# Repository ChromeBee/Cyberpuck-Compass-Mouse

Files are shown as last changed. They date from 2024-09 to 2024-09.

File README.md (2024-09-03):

<h2>Description</h2>
In the late 90's / early 2000's, I bought a Forte VFX1 headgear VR headset second hand from Cash Converters. This came with a hand device they called a Cyberpuck. Both the VFX1 
and the Cyberpuck used the Earths magnetic field to determine movement. In the VFX1 this determined where the wearer was looking and in the 
case of the Cyberpuck, what hand movements the user was making.

Cyberpuck
<i>Original Cyberpuck from 1995. (Wikipedia free use image)</i>

cropped image Cyberpuck in hand
<i>My version of the cyberpuck 2024</i>

This is my version of the Cyberpuck, upgraded to be wireless. I was inspired to develop this based on an Element14 video I watched where Clem
tries to make a mouse using an IMU sensor but ends up with something you have to pick up and twist and tilt to get working.  I though, that is 
like the old Cyberpuck I used to have. 

The Cyberpuck is a 2DOF mouse that uses pitch to move the mouse pointer up and down the screen and roll to move it left and right. I can't 
remember how I used the original version but for this one, the mouse only moves if the lower button (GPIO2) is pressed. This is so you can set
it down with the mouse pointer moving unintentionally. The top button (GPIO4) provides the left mouse button functionality while the middle
button (GPIO3) is the right mouse button. <i>Please note that there is additional informations below the built instruction for those that want it.</i>

<h2>Assemby Instructions</h2>

<b>Parts List:</B>
<ul>
<li>XIAO ESPC3 micro controller</li>
<li>GY-271 - Compass sensor</li>
<li>3 6x6x5mm tactile switches</li>
<li>connecting wire</li>
<li>lipo battery with builtin BMS protection circuit of an appropriate size to fit in the case. I used a 501220.  
As you can see from the photos, there is space for a larger battery.</li>
<li>You will also need the 3D printed parts, 1 each of the side pieces and 3 of the buttons</li>
</ul>

<b>Wiring Diagram:</b>

wiring diagram

I bought all the parts except the battery from Amazon. The battery I bought from eBay.

I chose the XIAO ESP32C3 microcontroller because it was being advertised in my Google news feed at the time and I liked the small size. It has a
hardware UART (serial interface) which means that it can't simulate a mouse over the USB cable so Bluetooth has to be used. If you don't want to 
use the battery, it can be powered over USB but you still need to use Bluetooth to use it as a mouse. Other XIAO size micro controllers can be 
used but you'll need to modify the code if the pinouts are different.

photo of completed wiring

Keep the wires short when wiring things up so that everything fits inside the case.

photo of circuit in case

There is a lip to the right hand side of the bottom case where the battery is. The top lid has a matching part which slips below this lip and
using the USB access hole as a guide to ensure the two halves aren't twisted fold the two halves together. There are protrusions on the top
half of the case that fit down the side of the switches and hold it closed.

Once built download the sketch from this repositary page. The code uses two libraries. The QMC5883LCompass library so that the microcontroller can 
use the GT-271 sensor and a BLEMouse library so it can act as a Bluetooth mouse. Download the one at 
https://github.com/sirfragles/ESP32-BLE-Mouse/tree/dev The official BLEMouse library fails to compile but this version has a fix installed.

To minimise battery drain when the mouse isn't being used, the ESP32C3 will go into a deep sleep state after 2 minutes of non use. Pressing 
any of the buttons will wake it up again. The battery is recharged by plugging the microcontrollers USB port into any 5v USB power source such as a computer or power bank .

With the Cyberpuck mouse awake, Open the Bluetooth settings on whatever device you want to use it with and scan for new devices. “Cyberpuck mouse”
should appear in the list as a mouse device. Connect to it, and holding the device in your hand with the middle buttons pointing forward and the
USB connector below, press the button connected to GPIO2 (the bottom button in my case and the bottom button in the wiring diagram), and move 
your arm up, tilting from the elbow and the mouse pointer should go up, tilting the device to the side should move the pointer to the left or 
right depending on the direction of the tilt.

Here is a short demonstration followed by the device being assembled.

https://youtu.be/AyjnlBCEP1o

I don't see this replacing the traditional mouse for word processing or spreadsheet work but more as a gaming or presentation control device. I
think it would be good in a simple flight simulator or as a weapon in a simple first person shooter. I have had fun playing online mouse games,
but I keep losing to people using a traditional mouse. Maybe it is because I need more practice (or maybe I'm crap at the games).

<h2>Additional Information</h2>

prototypes
<i> how many prototypes until the final design?</i>

The GY-271 compass magnetometer uses a QMC5883L digital compass chip. A lot of the listings for this sensor board list it as having a HMC5883L
chip. Some versions of this board also have HMC5883L written on them.
This caused me to lose a lot of time as both chips offer a similar function but have different I2C address. This resulted in me getting zeros back from the I2C interface. The chip on the PCB just had 5883 written on it.
I downloaded a sketch that allowed me to see which addresses were active on the I2C bus and from that I found out that the chip
must have been a QMC5883L.

The QMCX5883Lcompass library has an example file for calibrating the chip. This tries to get the maximum and minimum values while you wave the sensor
around 360 degrees in all directions. I tried this and also captured large volumes of X, Y and Z values into a spreadsheet to analyse it. The
values given from the three directional sensors on the chip have different maximum values and different maximum values in the negative and
positive directions. This is why calibration is necessary if you need accurate direction values.

I stopped this project for several months as I had to think how to convert the 3D vector created from the 3 perpendicular sensors readings to the mouse movement I wanted. It turned out I didn't need
to as all I need is a relative change. We only need 2 DOF for this. So provided the mouse is rotated around one of its axis, the relative change in
value will give you the direction and amount.

Given the orientation of the board in the case, a roll (tilt left or right) cause a change in the Y and Z axis readings . 
A pitch change causes a change in the X and Y axis readings. For the porpose of using this as a mouse we only need to look at the change in Z readings to determine how much to move the mouse pointer in the horizontal and in what direction. The X reading is used in the same way for 
vertical movements. We can ignore the Y readings in normal use. Yawing the mouse (rotating it about the vertical axis) does cause movement on both the horizontal and vertical directions. Preventing this would mean going back to the 3D vector maths and I personally don't think it is worth the effort. Limiting our hand movements to pitch and roll is the easiest solution.

I intended this to be a wired mouse so I was surprised to find that I couldn't do that because the microcontroller I chose had a hardware UART to
communicate over USB. This means that it couldn't send mouse emulation signals over that port. I'd have to change the microcontroller or use
bluetooth. So bluetooth it was. That also meant that there was no point using USB just for power. So I'd need to add a battery and battery saving
features. Such as detecting when the device has been idle for a period and putting it in a power saving mode and be able to wake up from that.

Mapping the values from the compass sensor to mouse movements was also an interesting challenge. We want the mouse pointer to move fast across the screen
but still be able to do delicate movements. For this reason there is an exponential type mapping between the compass sensor and the steps the mouse will take.
Small tilt movements take small steps but large tilt movements cause large steps to be taken. There is a wider range of movement allowed for
small steps than large steps. This is achieved by having a mapping table that contains more small steps and as the movement gets larger and
the steps get bigger, the number of entries in the mapping table get smaller. 

The mapping table is sized based on the sum of integers up to a certain number. For ease of giving an example, i'll use the number 4. In this
case the mapping table would have 10 entries (4+3+2+1 = 10), The first 4 entries in the mapping table are filled with 1, the second 3 are filled with 2 the third 2 are filled with 3 and the last one is filled with 4. These numbers represent the number of steps the mouse will take
if that mapping entry is selected. We then need to take a reading from the compass, multiple that by 10 and divide the result by what we think is the largest number the compass can return (- the deadzone). Convert that into an integer and you should get a number between zero and ten. that we can then use to look up a mouse movement amount in the mapping table.

I might add something to the code to emulate even smaller steps. Such as emulating half steps by making the mouse only take a step every second time through the main loop for very small mouse movements. <b>update</b> I now think that the small steps are fine (comparing it to my other mouse) but I need a slower acceleration, i.e. more small steps before it starts to take bigger steps. I have added that to the code already.

Another thought I had was to have a click on and click off for mouse movements. I added that to the code but didn't like it in use. At first it seemed an improvement but I couldn't easily tell if it was on or off, so I removed it again.

I was playing the 3D maze game at https://www.chrisraff.com/3d-maze/ This is a fun game. I played it using the cyberpuck and an ordinary mouse and I found I had better scores with the cyberpuck. Finally I've found something that it is better at than a normal mouse (at least for me). 

I am still learning to use this. I keep moving my arm horizontally to move the mouse in that direction. That is not how the mouse currently works as the maths is far more complicated. And the original worked the same way mine does. Maybe I'll revisit it at some point.

<h2>License</h2>
Shield: [][cc-by-nc-sa]

This work is licensed under a
[Creative Commons Attribution-NonCommercial-ShareAlike 4.0 International License][cc-by-nc-sa].

[][cc-by-nc-sa]

[cc-by-nc-sa]: http://creativecommons.org/licenses/by-nc-sa/4.0/
[cc-by-nc-sa-image]: https://licensebuttons.net/l/by-nc-sa/4.0/88x31.png
[cc-by-nc-sa-shield]: https://img.shields.io/badge/License-CC%20BY--NC--SA%204.0-lightgrey.svg

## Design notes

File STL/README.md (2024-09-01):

STL files from the design ready for 3D printing can be found here.

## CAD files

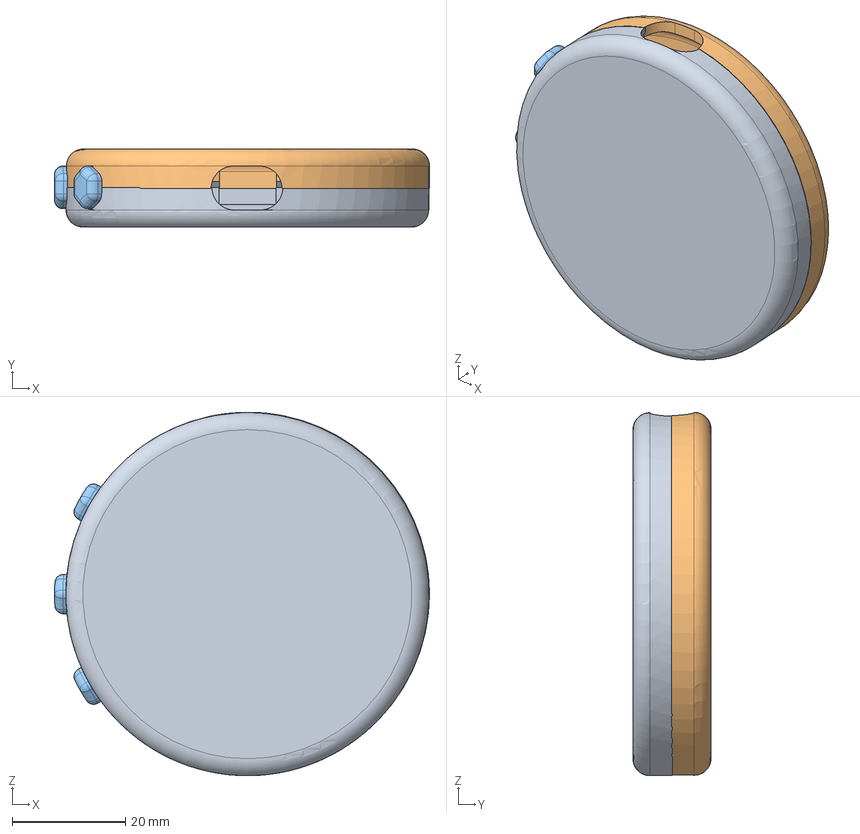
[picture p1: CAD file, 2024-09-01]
Design/Cyberpuck Compass Mouse.step
66.1 x 13.8 x 64.1 mm
side
side 2
button

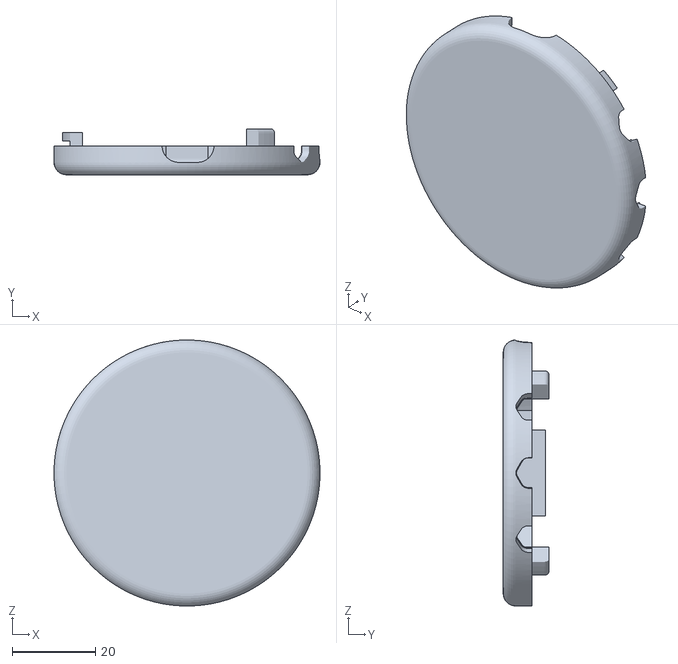
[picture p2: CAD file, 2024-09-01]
STL/compass mouse side 2.stl
64.0 x 11.0 x 64.0

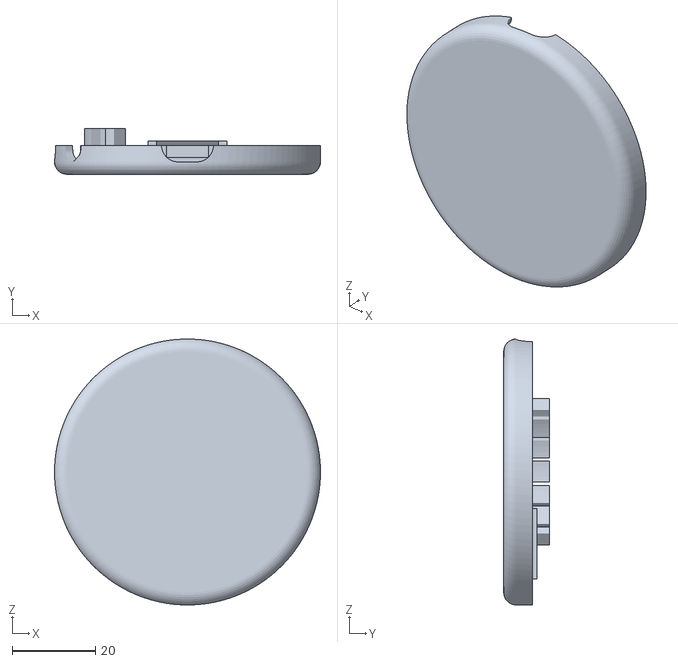
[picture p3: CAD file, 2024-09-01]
STL/compass mouse side.stl
64.0 x 11.0 x 64.0

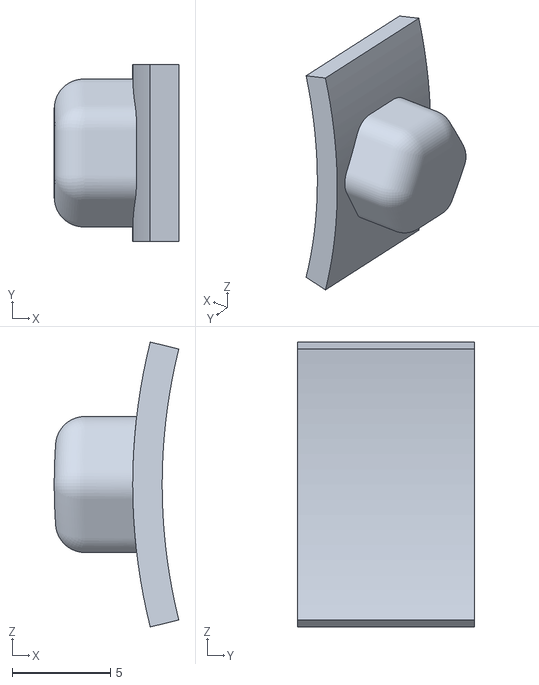
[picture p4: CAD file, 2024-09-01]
STL/button.stl
6.35 x 9.00 x 14.5

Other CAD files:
Design/Cyberpuck Compass Mouse.f3d

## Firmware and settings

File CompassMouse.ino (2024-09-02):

// Compass Mouse
// A modern version of the Forte Cyberpuck from the 1990s
// The Cyberpuck was an input device for the Forte VFX1 Headgear VR headset.
// Both the headset and the cyberpuck used the earths magnetic field to determine movement.
// in the headsets case it was used to determine where the user was looking and in the Cyberpucks case, how they moved their hand.
// It was a 2 DOF device using pitch and roll to map to Y and X.
// As well as using it with the VFX1 headset, it could be used alone as a mouse that didn't need desk space.
// this is my modern interpretation of the Cyberpuck device.
// i'm using aSeeed Studio XIAO ESP32C3 as the microcontroller and GY-271 magnetometer sensor board to detect the earths magnetic field
// it uses the QMC5883 compass sensor.
// 3 6x6x5mm tactile buttons are also used to simulate mouse buttons. All came from Amazon in the UK.
//
// This sketch needs the QMC5883LCompass library and a BleMouse library
// The default BLEMouse library doesn't compile due to change in the arduino string type introduced some time ago. Use the library below instead
//  https://github.com/sirfragles/ESP32-BLE-Mouse/tree/dev
//
/*--------------------------------------------------------------
 * Change log
 * C001 01-Sep-2024 - lengthened the mapping array to give double the space to each step value to make acceleration slower
 * -------------------------------------------------------------
 */
#include <BleMouse.h>
#include <QMC5883LCompass.h>
#include "driver/rtc_io.h"




#define MAX_COMPASS_VALUE 600.0 // assumed maximum from compass read once deadzone value is removed
#define MAX_MOUSE_MOVEMENT 7 // Maximum single step for mouse. This is what it takes when compass output is MAX_COMPASS_VALUE or higher
#define MOVEMENT_BUTTON 0 // button that enables mouse movement
#define LEFT_BUTTON 2 // button that simulates left mouse button pressed
#define RIGHT_BUTTON 1 // button that simulates right mouse button press

#define TIMEOUT 2*60*1000 // 2 minutes of inactivity will cause the ESP32 to enter deep sleep mode.

#define BUTTON_PIN_BITMASK  1ULL<<GPIO_NUM_2 | 1ULL<<GPIO_NUM_3 | 1ULL<<GPIO_NUM_4 // pins used for buttons. need bit mask for wakeup action.
gpio_num_t BTNLIST[3] = { // Button pin list - note that BUTTON_PIN_MASK will need changed if this list changes
  GPIO_NUM_2,
  GPIO_NUM_3,
  GPIO_NUM_4
};

static bool reverseX = true; // reverse mouse X direction if true
static bool reverseY = true; // reverse mouse Y direction if true

#define BLUETOOTHTIMEOUT 5*1000 // time connection is allowed to drop before trying to pair with another device
QMC5883LCompass compass;
static std::string deviceName = "Cyberpuck mouse";
BleMouse bleMouse;
// C001 - doubled the size of the map_array as it will have double the number of each value original formula was MAX_MOUSE_MOVEMENT*(MAX_MOUSE_MOVEMENT+1)/2 this is the formula for the sum of all integers upto MAX_MOUSE_MOVEMENT
int map_array[MAX_MOUSE_MOVEMENT*(MAX_MOUSE_MOVEMENT+1)]; // array that is the size all the interger values from MAX_MOUSE_MOVEMENT added together down to zero. i.e. if this were 3 it would equal 3+2+1+0

//-------------------------------------
// convert from compass value to mouse movement value
// the map_array is filled in the setup subroutine to favour small movements
int mapToMovement(float input, float max_output,float max_input) {
  int output;
  int max_index = (int)(max_output*(max_output+1)); // Size of the map array C001 - removed the divide by 2 in the integer addition formula
  
  output = input*max_index/max_input; // find the array index to use (this may be negative indicating the looked up value must be the same)
  int sgn=output/abs(output); // get the sign of the value (this gives either 1 or -1)
  //Serial.print("array index ");Serial.println(output);
  output = (abs(output)>=max_index) ? sgn*map_array[max_index-1] : sgn*map_array[abs(output)]; // check that the result is not too large then look up the step size to take
  
  return output; // return mouse step size
}

//-----------------------------------
// read buttons with debounce code included
#define DEBOUNCE_TIME 50 // number of milliseconds allowed to reach steady state
unsigned long timeSinceChange[3] = {0,0,0}; // milliseconds since switch state last changed
uint8_t lastKnownState[3] = {0,0,0}; // remember old switch state.
bool stateChanged[3] = {false,false,false};

void readAllFromButtons(uint8_t *buttonValues){
  for(int i=0; i<3; i++){ // read button values
    buttonValues[i] = !gpio_get_level(BTNLIST[i]);
    stateChanged[i] = false;
    if(buttonValues[i] != lastKnownState[i]) {
      if(millis() - timeSinceChange[i] > DEBOUNCE_TIME) {
        lastKnownState[i] = buttonValues[i]; // sufficient time has passed to accept this a the new switch state
        timeSinceChange[i] = millis();
        stateChanged[i] = true;
        Serial.print("button ");Serial.print(i);Serial.println(" pressed");
      } else {
        buttonValues[i] = lastKnownState[i]; // keep the old state as this could be a bounce
      }    
    }
  }
}

//---------------------------------------
void setup() {
  Serial.begin(115200);
  //delay(3000);
  int k = 0;

  // fill map array with steps to be taken. Small movements occupy more of the array than big movements to give more control
  // if MAX_MOUSE_MOVEMENT were to be set to 3, then the array would be filled with 1,1,1,2,2,3
  // The map to movement function uses this to determine how big a mouse movement to make for a particular angle.
  // C001 - in example now filling with 1,1,1,1,1,1,2,2,2,2,3,3 - to reduce mouse acceleration
  for (int i = 0; i<MAX_MOUSE_MOVEMENT; i++) {
    for (int j = 0; j<MAX_MOUSE_MOVEMENT-i; j++) {
      for (int m = 0; m<2; m++) {  // C001 - double each map values entries
        map_array[k++] = i+1;
        Serial.print(i+1);Serial.print(",");
      }
    }
  }
  Serial.print(" Array Size = ");Serial.println(k);

  // enable the buttons with pull ups (using rtc functions)
  for( int i = 0; i < 3; i++) {
    gpio_set_direction(BTNLIST[i],GPIO_MODE_INPUT);
    gpio_pulldown_dis(BTNLIST[i]);
    gpio_pullup_en(BTNLIST[i]);
  }

  // enable deepsleep to save battery
  esp_deep_sleep_enable_gpio_wakeup(BUTTON_PIN_BITMASK,ESP_GPIO_WAKEUP_GPIO_LOW);

  
  Serial.println("Starting BLE work!");
  bleMouse.deviceName = deviceName;
  bleMouse.begin();
  compass.init();
  compass.setCalibration(-1920,1275,-1850,1503,-1288,1912); // maximum and minimum values determined through manual testing - may not be needed for mouse function

}

//----------------------------------------
float cx = 0,cy = 0,cz = 0;
float deadzone = 200;
float mx ,my ,mz;
int sx,sy;
bool bleFirstConnect = true;
unsigned long timeSinceActive=millis(); // mouse inactivity timer
unsigned long bluetoothConnectionTimeout = 0; // bluetooth connection drop time

void loop() {
  float x, y, z;
  double xy,xz,yx,yz,zx,zy;
  uint8_t buttonReads[3];
  float sgn;

  
  if(bleMouse.isConnected()) {
    if (bleFirstConnect) { // this is just so we only print out that we have a connection the first time we connect. subsequent times through the loop we should still be connected
      Serial.print(bleFirstConnect);Serial.print("BLE Connected");
      bleFirstConnect = false;
      Serial.println(bleFirstConnect);
    }

  
    // button values true or false
    readAllFromButtons(buttonReads);

    if (buttonReads[MOVEMENT_BUTTON]) {
      compass.read();

      // Return XYZ readings
      x = float(compass.getX());
      y = float(compass.getY()); // only using x and z compass axis. May use this for getting the max and min values if needed for calibration
      z = float(compass.getZ());
      
      // set up centre coordinates if not set already - these are removed from subsequent readings to get direction of movement
      if ((abs(x)>0) && (cx == 0)) {
        cx = x; cz = z;
      }
      
      if (cx != 0) { // if we have already set a center value for the axis,  the movement value is the actual value minus the center value
        mx = x - cx; mz = z-cz;
      }
      // there is a dead zone in the middle to allow for fluctuations in the readings. If reading is between plus and minus of the deadzone value, ignore it
      // I can rework this section as only the else section is required for movement
      if (abs(mx)<deadzone){
        mx = 0;
        sy = 0;
      } else {
        sgn = mx/abs(mx);
        mx = (reverseX ? -1.0 : 1.0)*sgn*(abs(mx)-deadzone); // the -1 in the front reverses the direction of the movement
        sy = mapToMovement(mx,MAX_MOUSE_MOVEMENT,MAX_COMPASS_VALUE); // map the compass value to a mouse movement value

      }
      if (abs(mz)<deadzone){
        mz = 0;
        sx = 0;
      } else {
        sgn = mz/abs(mz);
        mz = (reverseY ? -1.0 : 1.0)*sgn*(abs(mz)-deadzone);
        sx = mapToMovement(mz,MAX_MOUSE_MOVEMENT,MAX_COMPASS_VALUE);  // map the compass value to a mouse movement value

      }

      // for debug, write out the movement values
      Serial.print("MX = ");
      Serial.print(mx);
      Serial.print(" MZ = ");
      Serial.println(mz);
      
      bleMouse.move(0,sy);
      Serial.print("Scroll vertical "); Serial.print(sy); // for debug

      bleMouse.move(sx,0);
      Serial.print(" Scroll horizontal "); Serial.println(sx); // for debug

      timeSinceActive = millis();  // reset inactivity timer
      } else {
        cx = 0; // reset mid point each time button is released. When  the button is pressed again a new neutral position is calculated
      }

    // check for mouse button presses  
    if ((buttonReads[LEFT_BUTTON]) && (stateChanged[LEFT_BUTTON])) {
      Serial.println("Left button pressed");
      bleMouse.press(MOUSE_LEFT);
      timeSinceActive = millis();  // reset inactivity timer
    } else if (stateChanged[LEFT_BUTTON]) {
      Serial.println("Left button released");
      bleMouse.release(MOUSE_LEFT);
    }
    
    if ((buttonReads[RIGHT_BUTTON]) && (stateChanged[RIGHT_BUTTON])) {
      Serial.println("Right button pressed");
      bleMouse.press(MOUSE_RIGHT);
      timeSinceActive = millis();  // reset inactivity timer
    } else if (stateChanged[RIGHT_BUTTON]) {
      Serial.println("Right button released");
      bleMouse.release(MOUSE_RIGHT);
    }
    bluetoothConnectionTimeout = millis(); // record that we have an active bluetooth connection
  } else { // BLE disconnected
    if ((bluetoothConnectionTimeout != 0) && ((millis() - bluetoothConnectionTimeout) > BLUETOOTHTIMEOUT)) { // If we have had a connection and the last time we had it is greater than the timeout value
      //bleMouse.end(); // close the current connection
      //delay(500);
      //bleMouse.begin(); // try to reconnect - either with the same device if still paired or a new one.
      //bluetoothConnectionTimeout = 0; // record that we don't have an active connection. (stops this section being called again)
      //bleFirstConnect = true; // set this so that a new connection can be printed on the serial monitor
      ESP.restart(); // using this as the bleMouse.end function doesn't release all bluetooth resorces
    }
  }
  // check inactivity timer. Is it beyond the threshold value
  //Serial.print("Current inactivity timer ");Serial.println(millis() - timeSinceActive);
  if (millis() - timeSinceActive > TIMEOUT) {
    Serial.println("Timeout exceeded - time to sleep"); // for debug
    esp_deep_sleep_start();
  }

}

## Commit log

2024-08-30 ESP32C3 sketch for Cyberpuck Bluetooth mouse
2024-09-01 Design file upload
    [Cyberpuck Compass Mouse.f3d, Cyberpuck Compass Mouse.step]
2024-09-01 Added STL files
    [button.stl, compass mouse side 2.stl, compass mouse side.stl]

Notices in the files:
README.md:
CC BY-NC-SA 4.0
